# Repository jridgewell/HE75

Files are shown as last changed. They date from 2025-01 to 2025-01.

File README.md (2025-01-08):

# HE75

A standard 60% kebyoard (GH60 compatible) with 75 hall effects keys and an ortholinear layout.

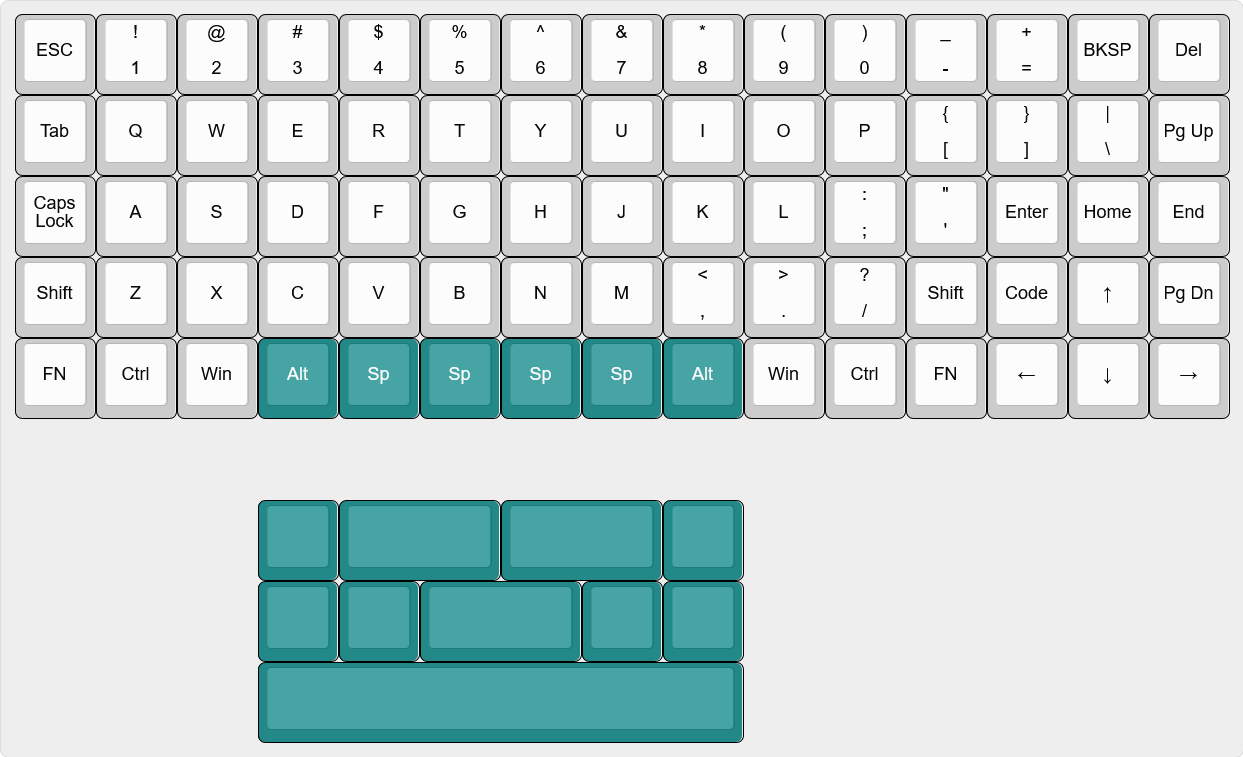
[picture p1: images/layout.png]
Keyboard Layout (https://www.keyboard-layout-editor.com/#/gists/170365ab19794ff094947c42b6bdc8db)

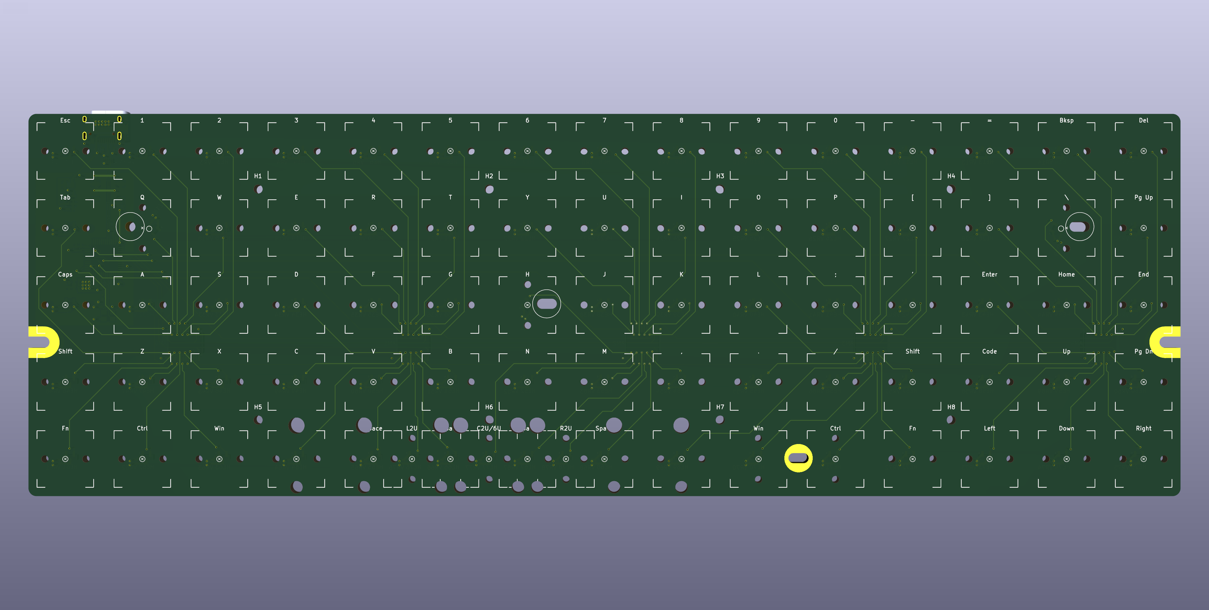
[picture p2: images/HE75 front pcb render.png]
Front PCB rendering

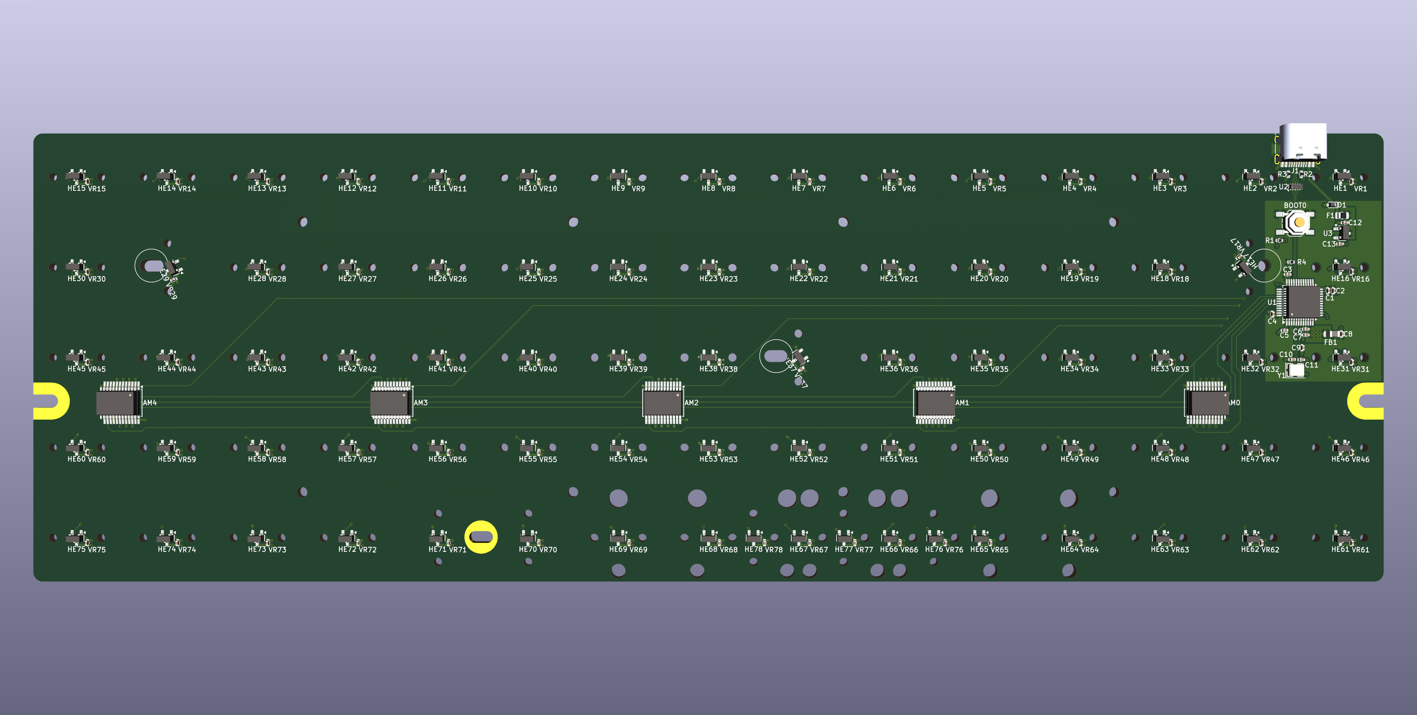
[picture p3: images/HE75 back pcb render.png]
Back PCB rendering


## Prior Art

While this keyboard is my own design, I pulled from many prior keyboard designs to figure out 60% layouts and how to layout hall effect sensors.

- [MoonBoard](https://github.com/certainly1182/MoonBoard), which I used heavily for routing patterns, schematic design, and even to find code to program QMK.
- [Void Switch 65%](https://github.com/riskable/void_switch_65_pct) (and the 2 begining videos [part 1](https://www.youtube.com/watch?v=TfKz_FbZWLQ) and [part 2](https://www.youtube.com/watch?v=sFR6E_Ejot0)), for giving me a starting point.
- [HE8](https://github.com/peppapighs/HE8) (and his [writeup](https://old.reddit.com/r/MechanicalKeyboards/comments/1glk0dc/i_made_a_hall_effect_macropad_long_writeup_below/)) to confirm components work.

I also used a few community assets to start the design:
- https://github.com/ebastler/marbastlib for switches and stabalizers footprints.
- https://github.com/ai03-2725/JP60 for an up-to-date GH60 shell layout.

# Constraints while designing

1. Must fit into a 60% keyboard case
2. Must use an ortholinear layout
3. Must use hall effect keys

I bought a [Wooting 60HE module](https://wooting.io/wooting-60he-module) and case, but I just can't stand the standard keyboard layout after using a split-ortho board for years. This is my attempt to cram an ortholinear layout into the same case, keeping it as close to a normal row staggered layout as possible. I do need occasional 1-handed access to right-hand side of the keyboard, I'm not after a mock split.

The first major issue is mouting positions for GH60 keyboards (marked in red):

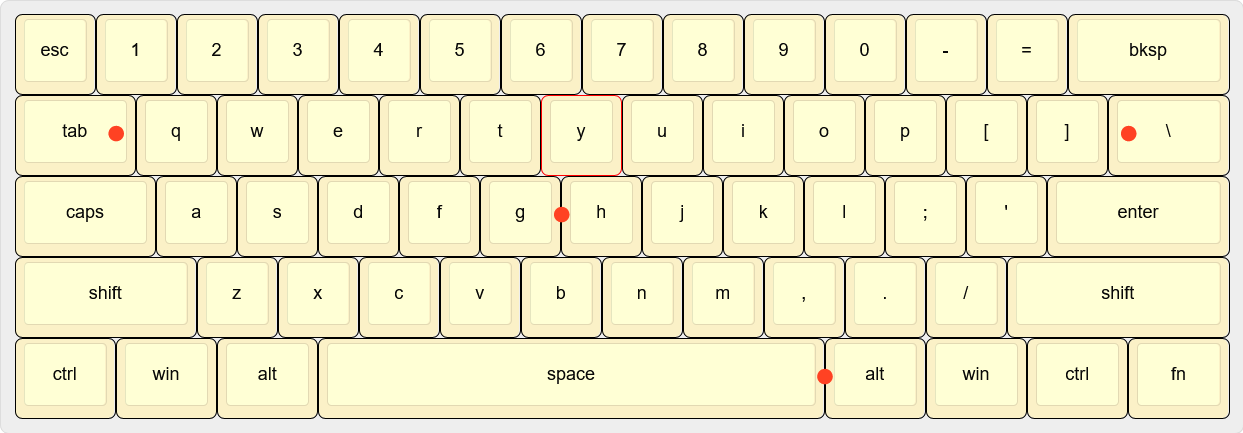
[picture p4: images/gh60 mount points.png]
GH60 mount points (https://www.keyboard-layout-editor.com/#/gists/9240d6fccecb17ad5743e3385da3a0a3)


When putting an ortholinear layout over top of that, several of the keys conflict:

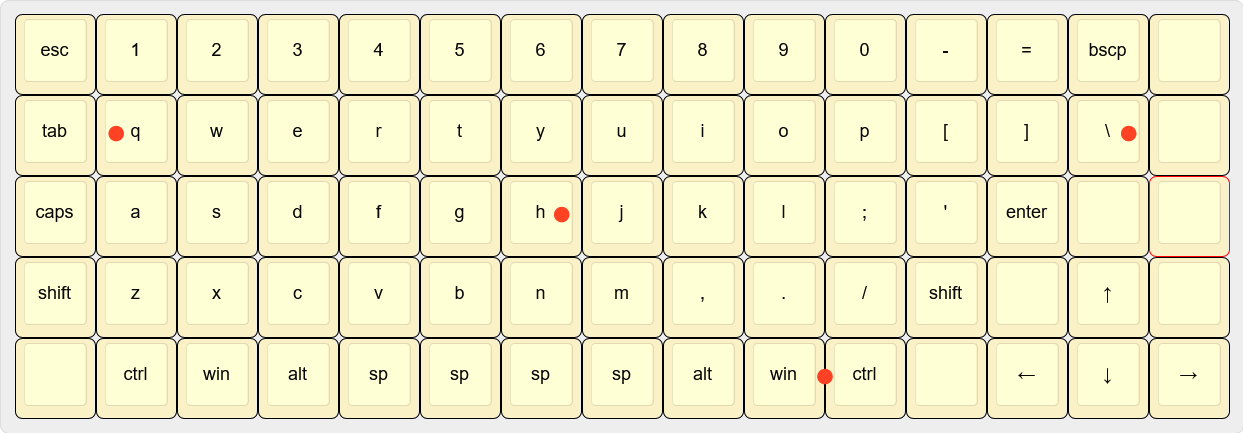
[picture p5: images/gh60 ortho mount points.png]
Ortho GH60 mount points (https://www.keyboard-layout-editor.com/#/gists/17eab835f870a1f1875c20cea78cf165)


If I were using standard MX key switches, this would only require rotating those keys 90% and skipping the screws in those locations. But with a hall effect keyboard, there's a hall effect sensor on the backside of the PCB occupying the same space as the screw mount. I need to move it so that it doesn't short out or get damaged when inserting the keyboard into the case. So for three keys (Q, H, and \), the sensor is roughly 1mm out of alignment with the key switch's magnet. Hopefully this'll be ok.

# Next Steps

I haven't ordered the first set of boards yet. JLCPCB estimates $47 for the first 5 PCBs, and $142 to get them assembled. I'm hoping someone will review the design before I send it off, I'm very new to this.

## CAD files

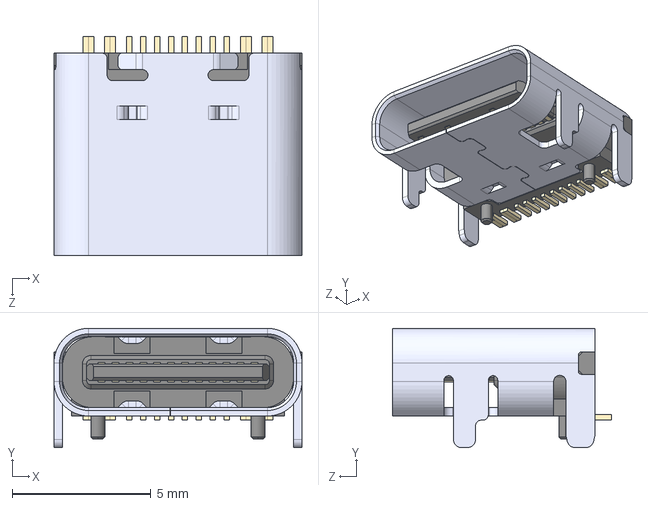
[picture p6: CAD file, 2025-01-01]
shapes3D/TYPE-C-31-M-12--3DModel-STEP-56544.STEP
8.94 x 4.30 x 7.90 mm

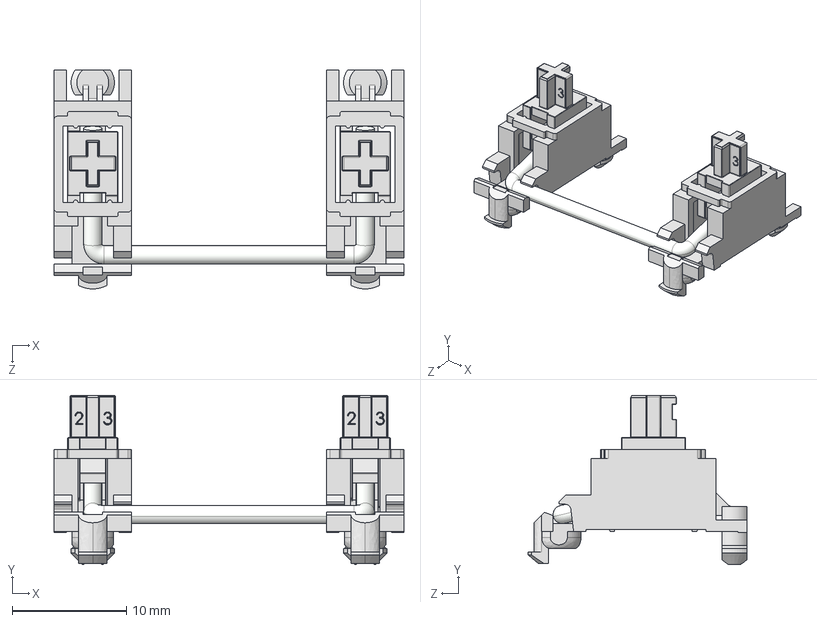
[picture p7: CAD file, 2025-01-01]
shapes3D/Stabilizer - close.STEP
30.7 x 14.9 x 19.2 mm
mx Stabilizer base 16828 x 2
mx Stabilizer key 16828 x 2
metal stick 16828

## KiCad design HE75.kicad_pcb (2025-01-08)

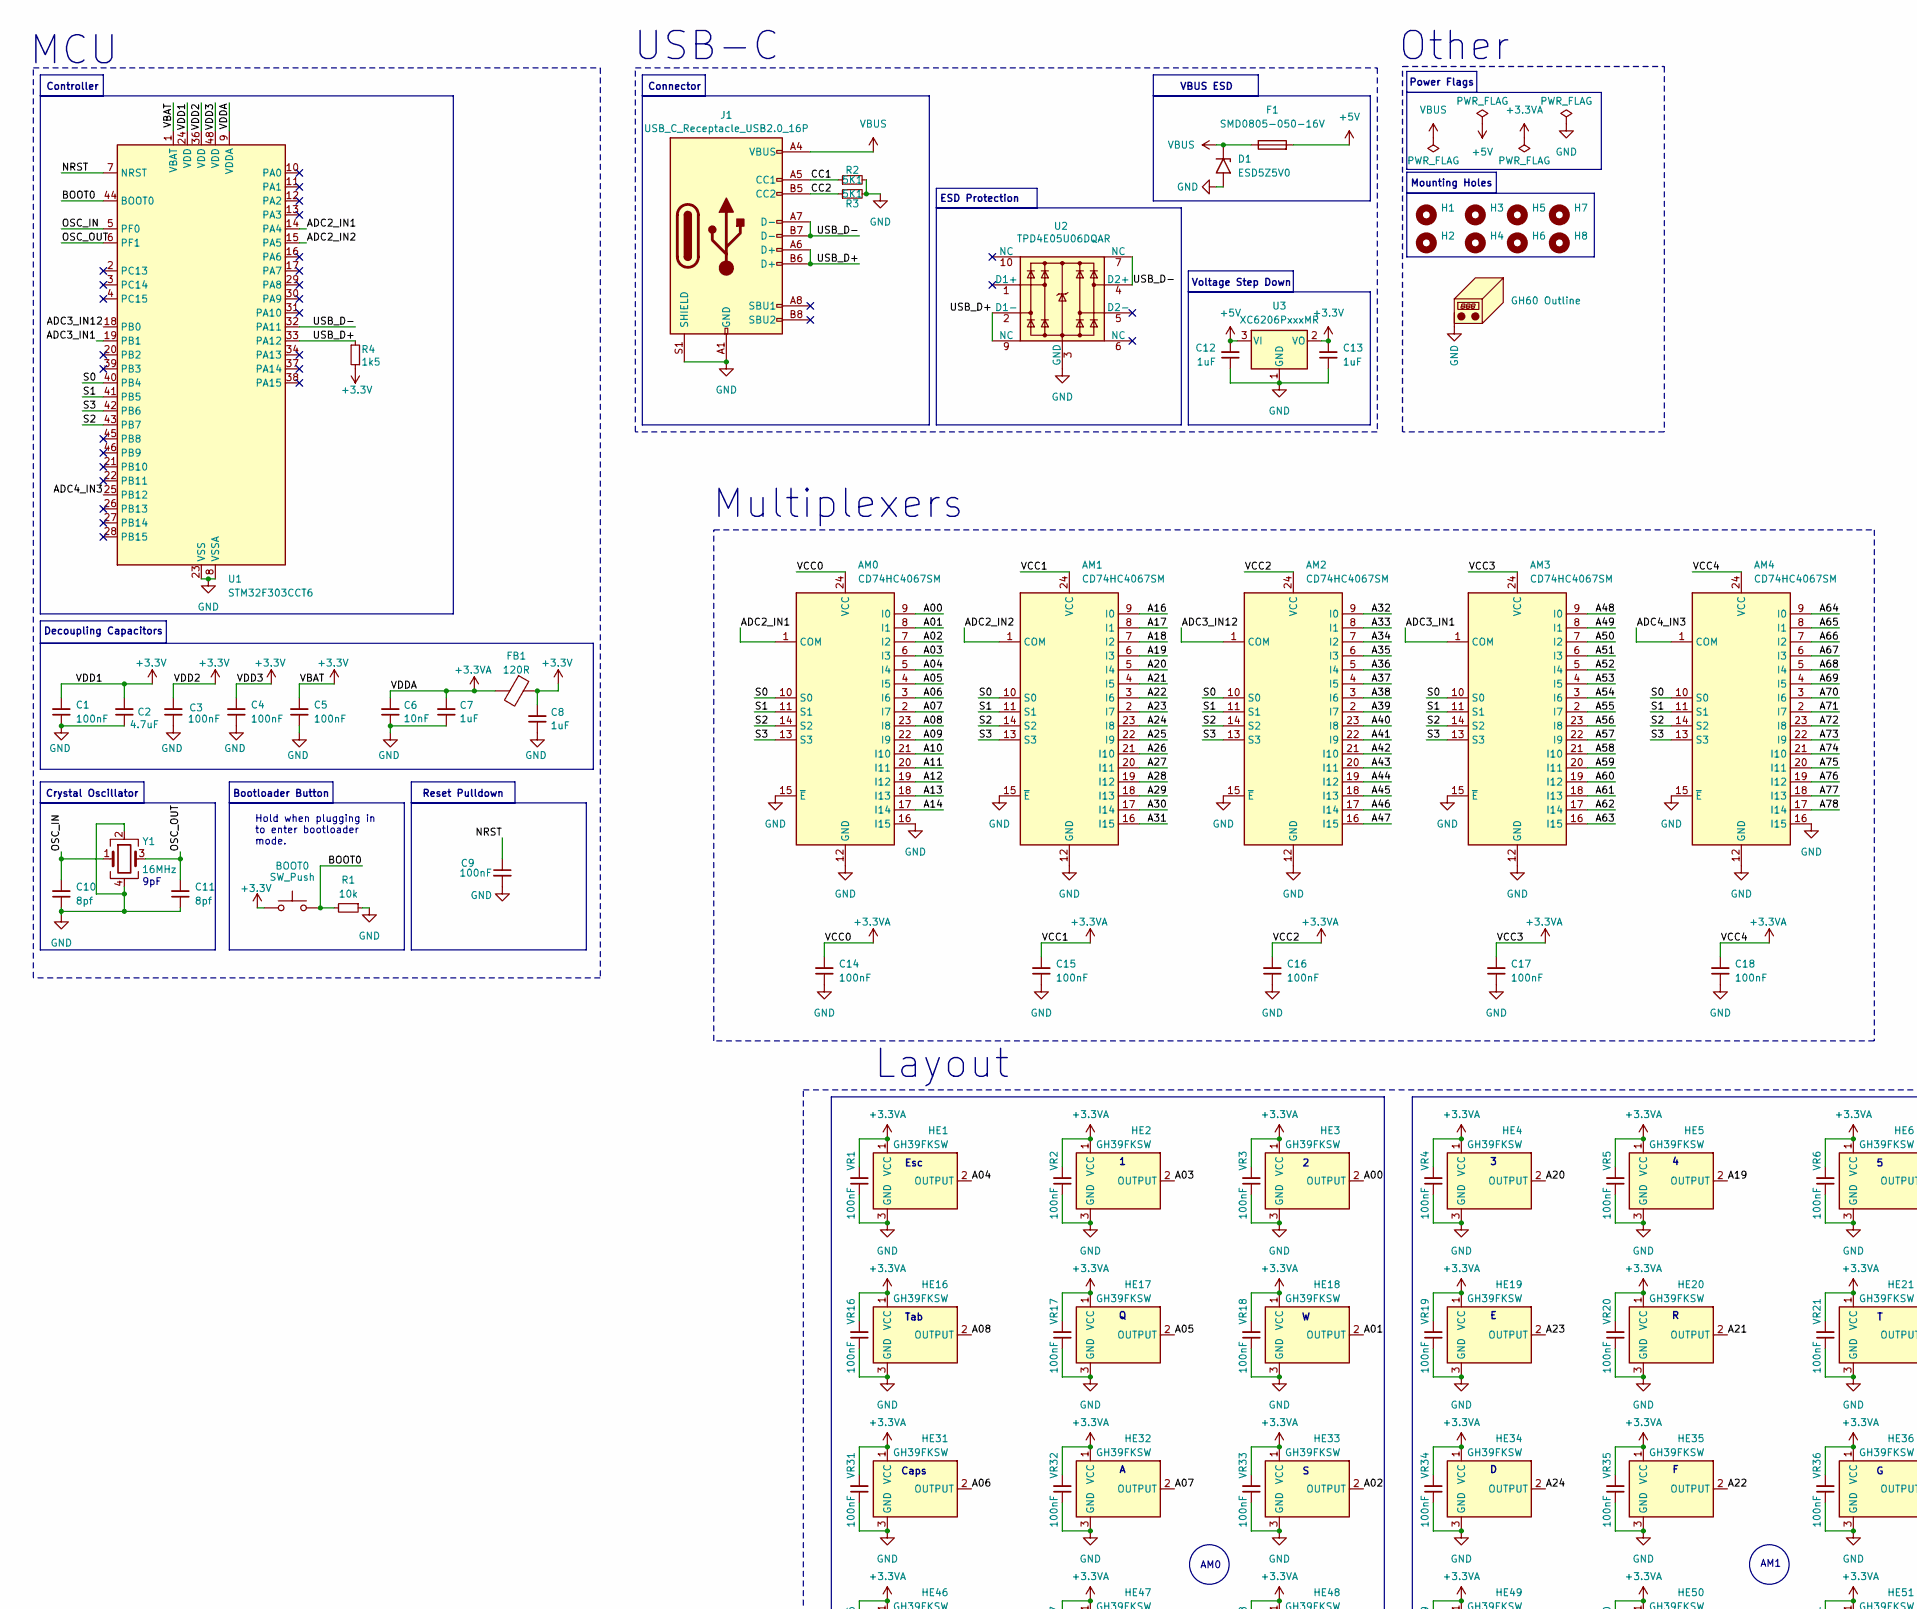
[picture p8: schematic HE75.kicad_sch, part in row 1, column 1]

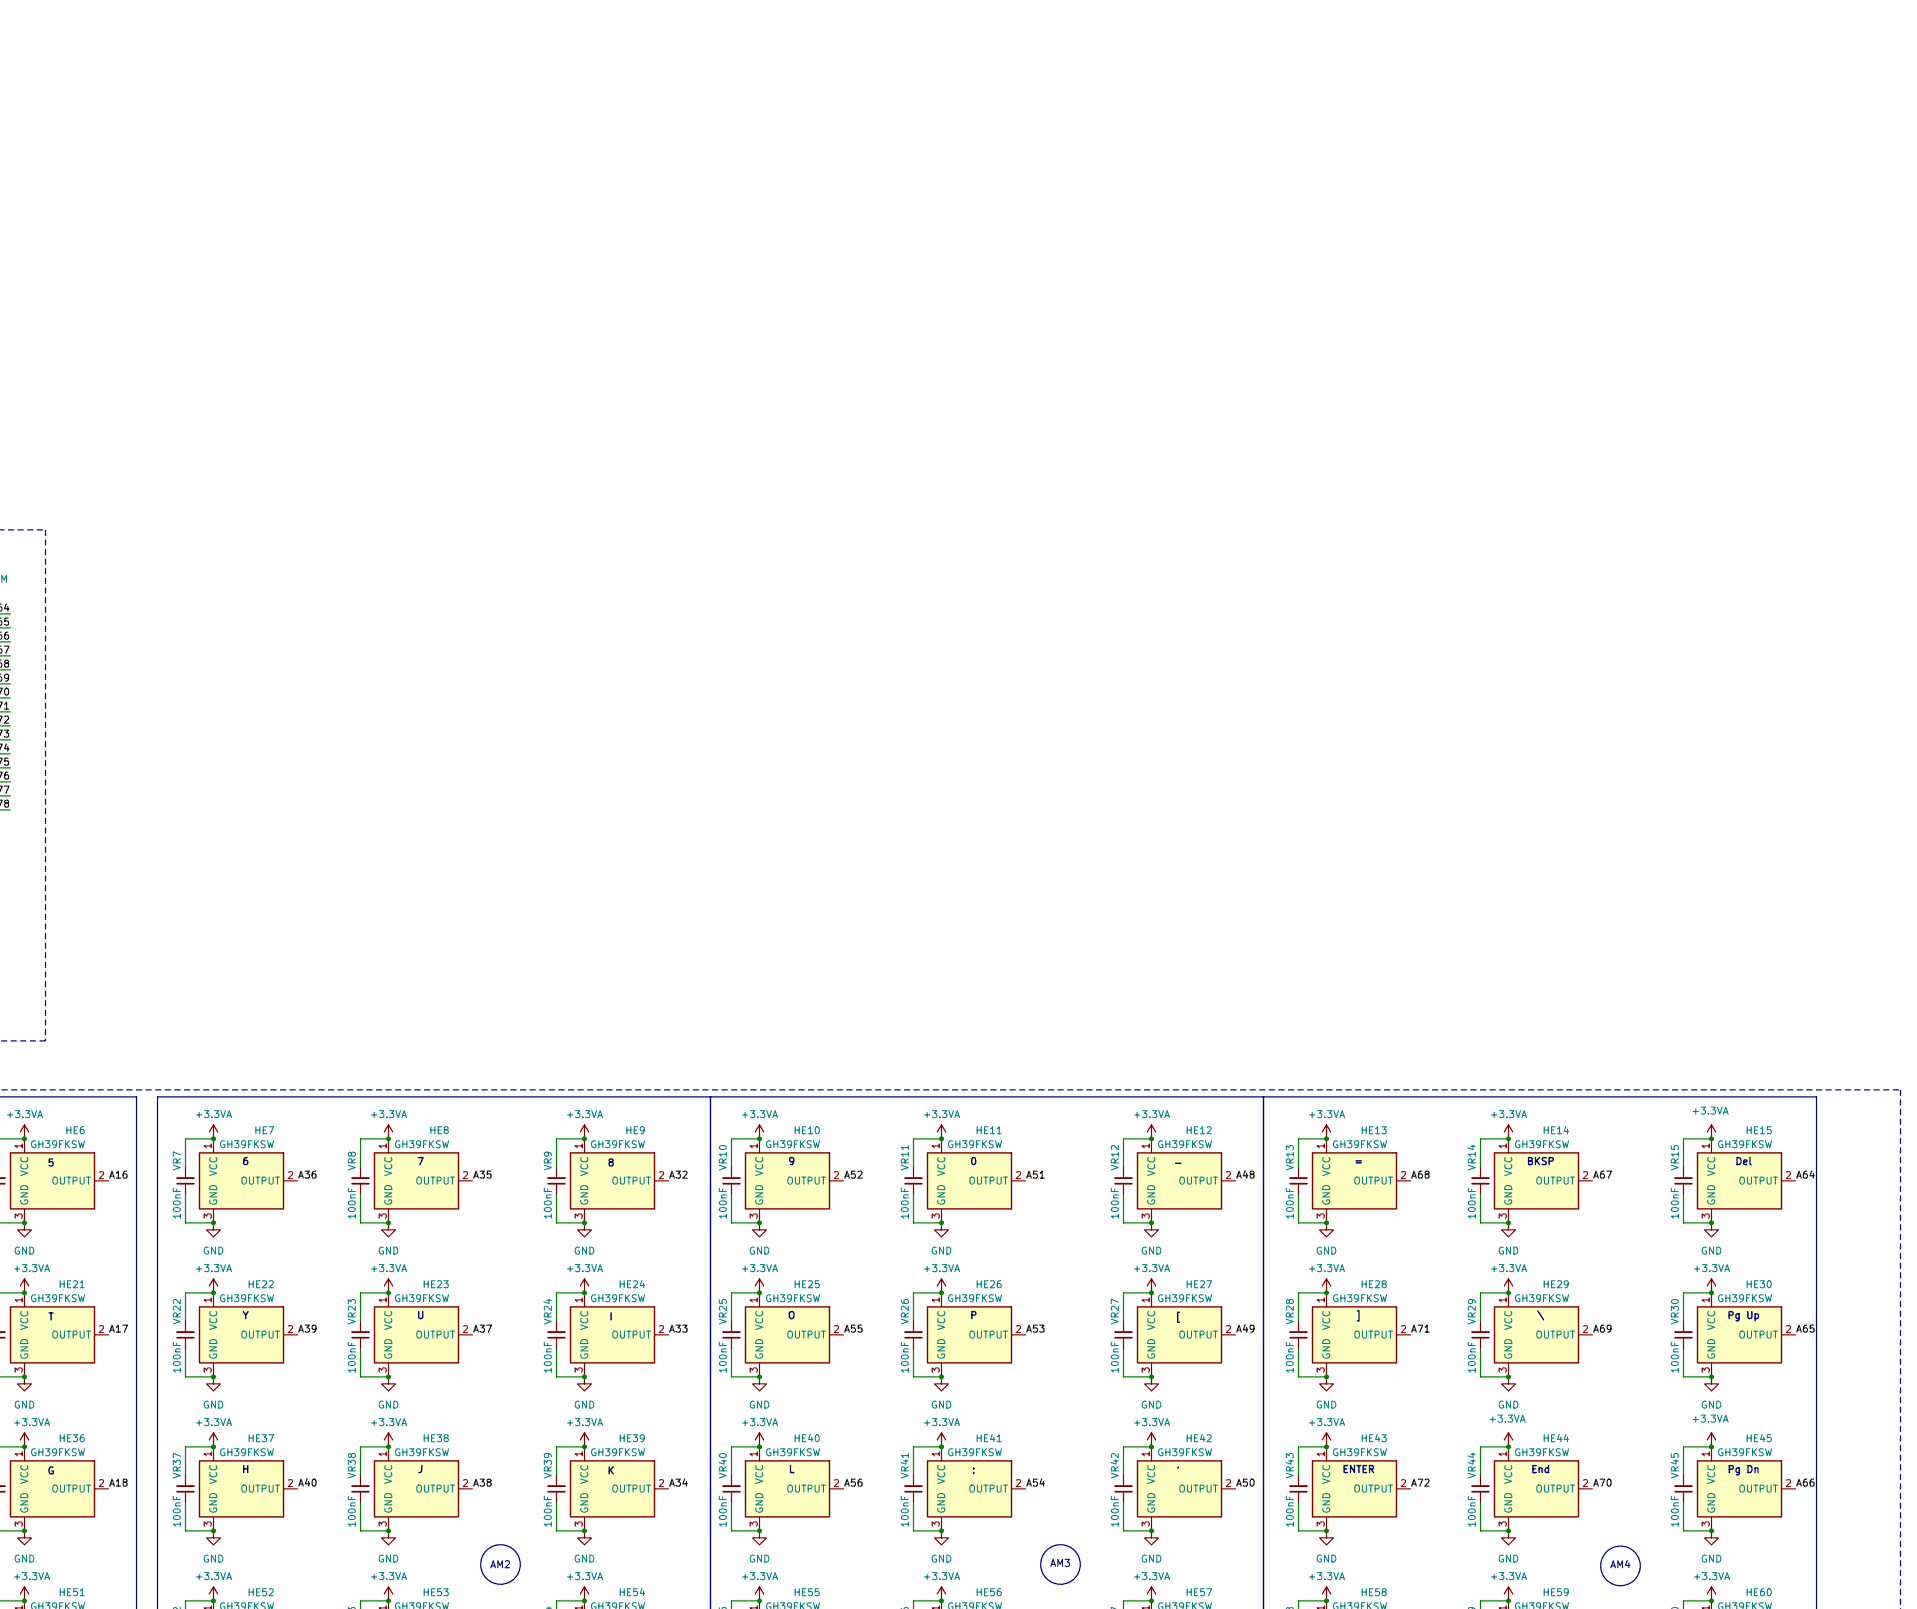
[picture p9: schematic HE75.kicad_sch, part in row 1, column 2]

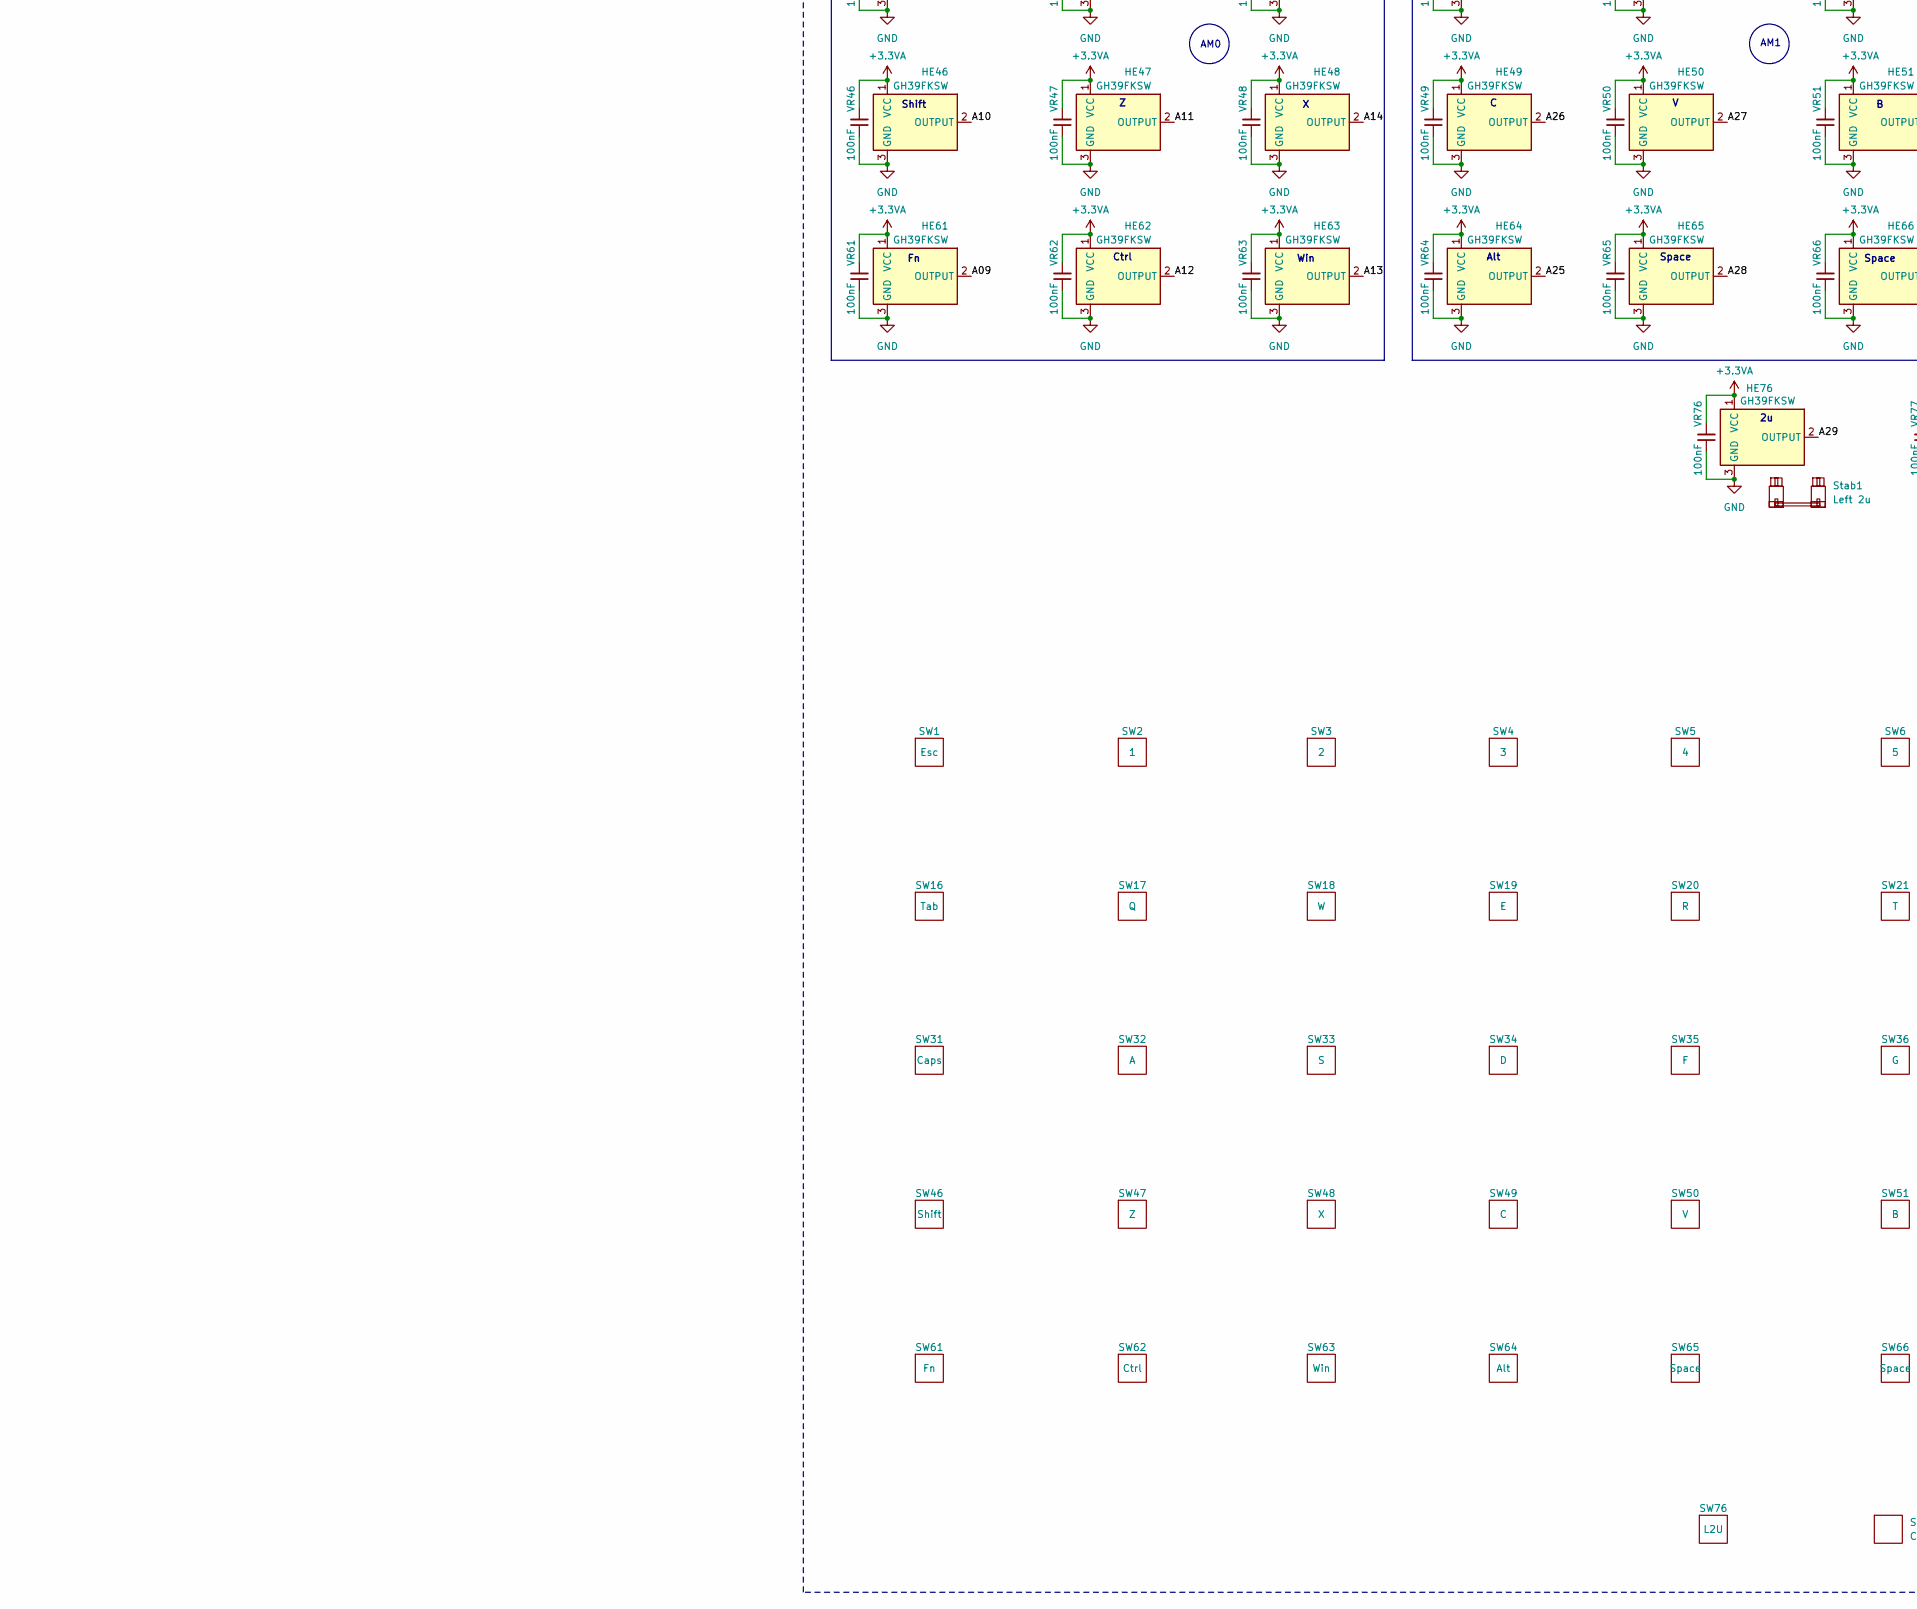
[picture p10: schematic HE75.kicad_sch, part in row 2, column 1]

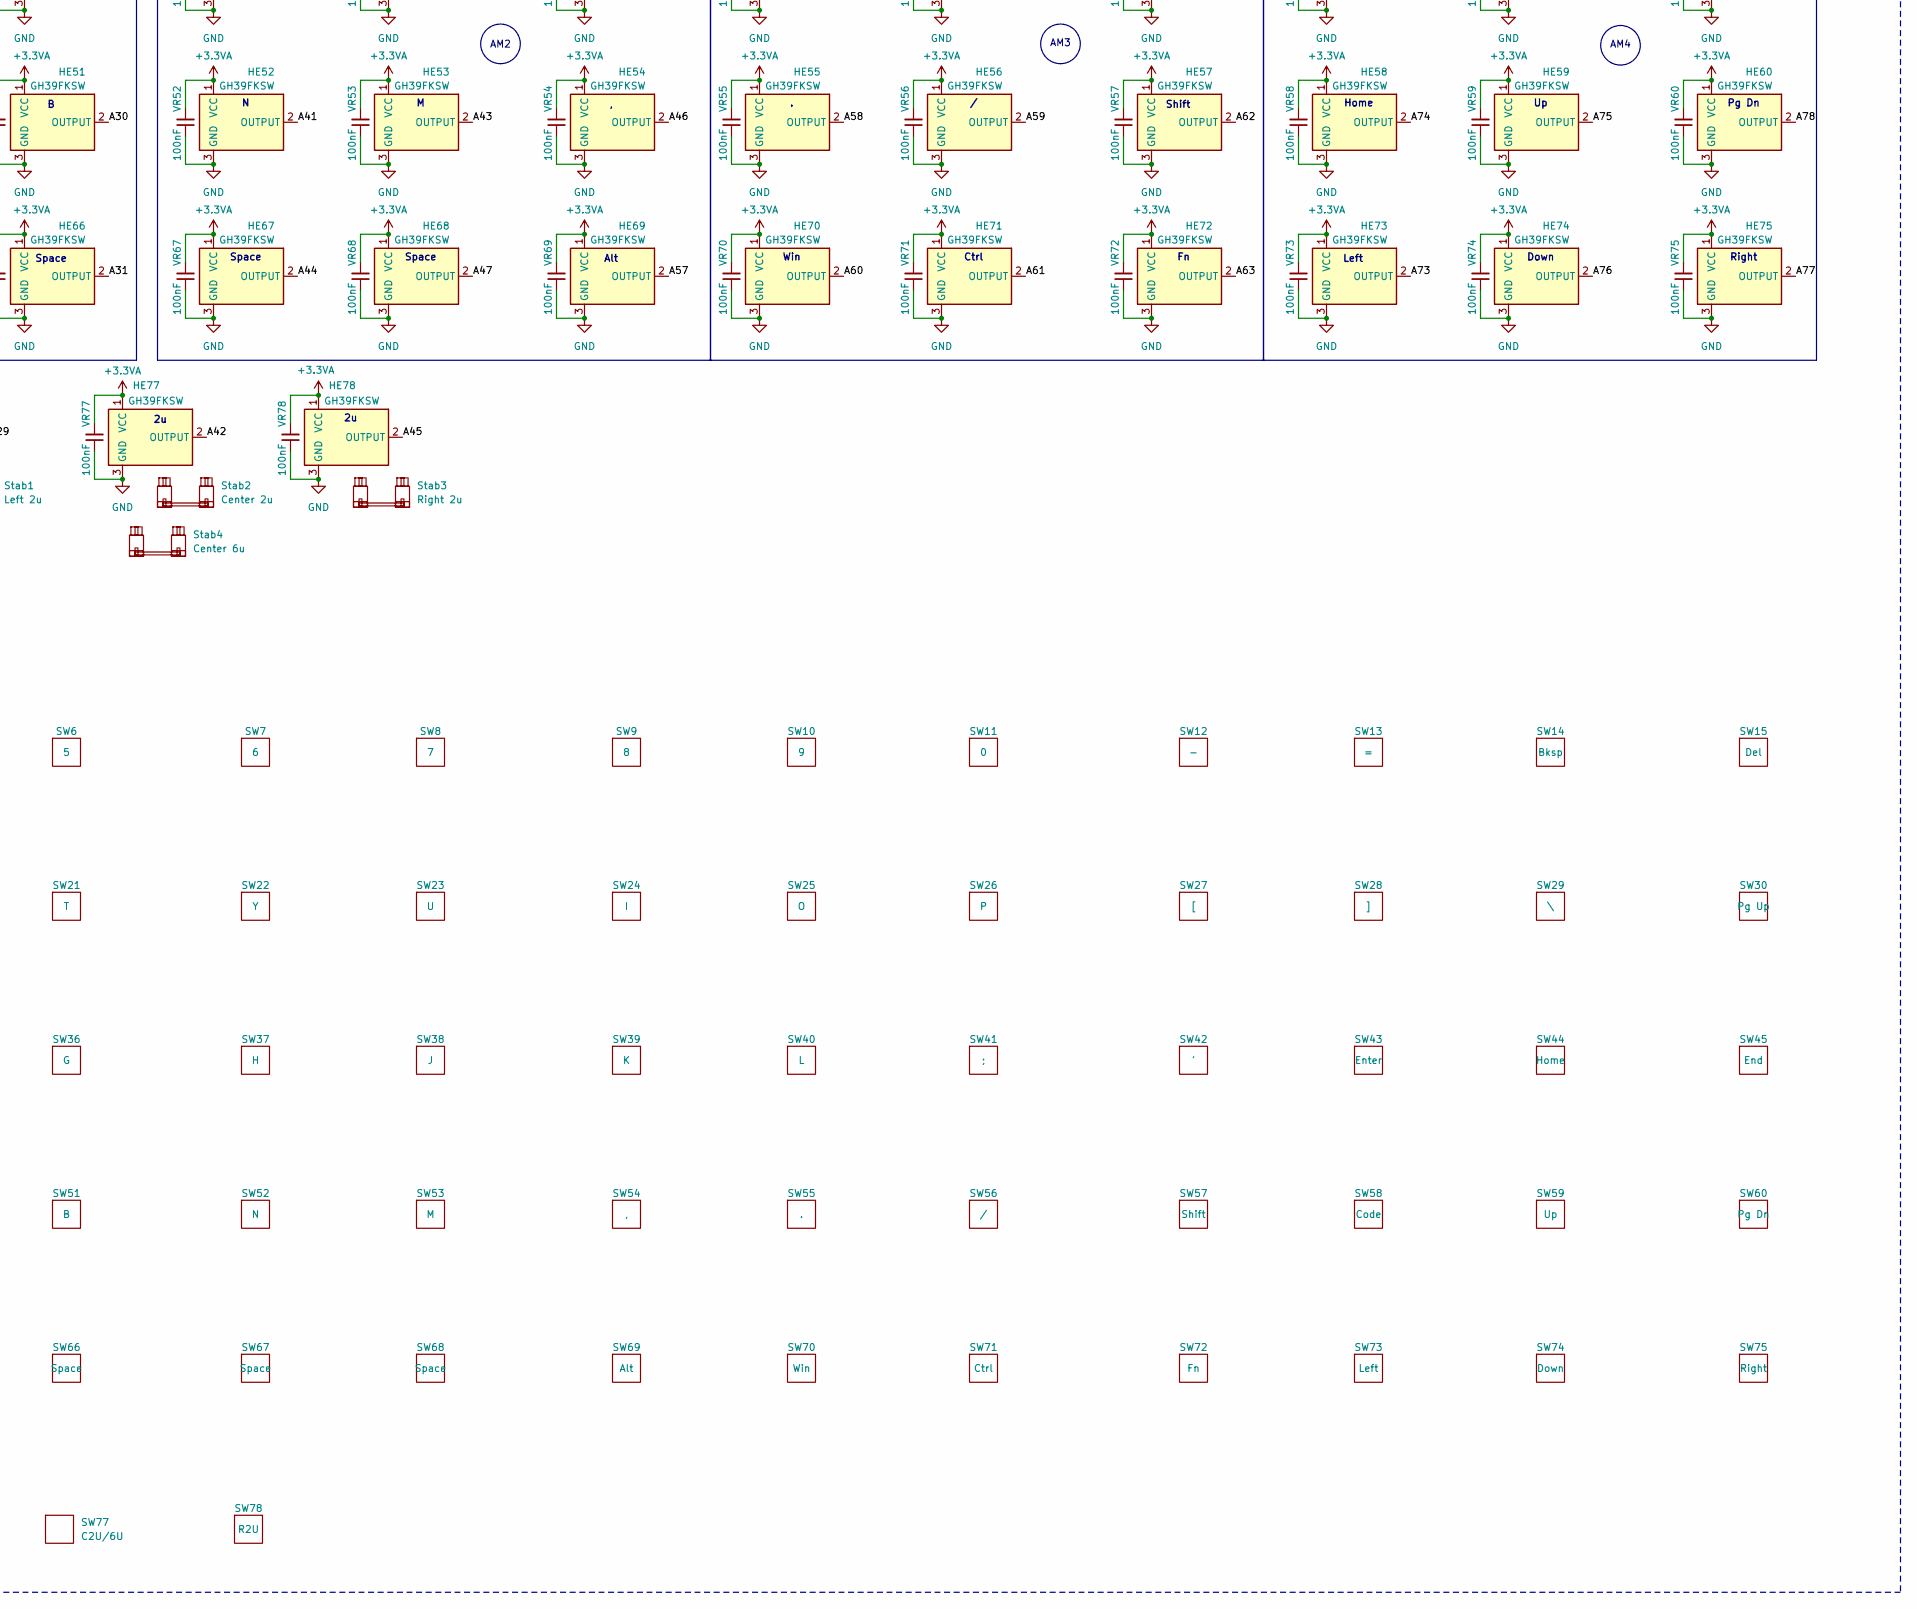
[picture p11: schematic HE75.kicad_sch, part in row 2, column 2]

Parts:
AM0, AM1, AM2, AM3, AM4: CD74HC4067SM; SSOP-24_5.3x8.2mm_P0.65mm; LCSC C98457
BOOT0: SW_Push; SW_SPST_TL3342; MPN SKQGABE010; LCSC C115351
C1, C3, C4, C5, C9, C14, C15, C16, C17, C18: 100nF; Capacitor 0402; LCSC C1525
C2: 4.7uF; Capacitor 0402; LCSC C23733
C6: 10nF; Capacitor 0402; LCSC C15195
C7, C8, C12, C13: 1uF; Capacitor 0402; LCSC C52923
C10, C11: 8pf; Capacitor 0402; LCSC C472443
D1: ESD5Z5V0; D_SOD-523; Manufacturer Part Number ESD5Z5V0; LCSC C502546
F1: SMD0805-050-16V; Fuse_0805_2012Metric; Manufacturer Part Number SMD0805-050-16V; LCSC C2833485
FB1: 120R; L_0805_2012Metric; LCSC C285922
H1, H2, H3, H4, H5, H6, H7, H8: MountingHole; MountingHole_2.2mm_M2
HE1, HE2, HE3, HE4, HE5, HE6, HE7, HE8, HE9, HE10, HE11, HE12, HE13, HE14, HE15, HE16, HE17, HE18, HE19, HE20, HE21, HE22, HE23, HE24, HE25, HE26, HE27, HE28, HE29, HE30, HE31, HE32, HE33, HE34, HE35, HE36, HE37, HE38, HE39, HE40, HE41, HE42, HE43, HE44, HE45, HE46, HE47, HE48, HE49, HE50, HE51, HE52, HE53, HE54, HE55, HE56, HE57, HE58, HE59, HE60, HE61, HE62, HE63, HE64, HE65, HE66, HE67, HE68, HE69, HE70, HE71, HE72, HE73, HE74, HE75, HE76, HE77, HE78: GH39FKSW; Hall Effect Sensor SOT-23; LCSC C266230
J1: USB_C_Receptacle_USB2.0_16P; USB_C_Receptacle_HRO_TYPE-C-31-M-12; MPN TYPE-C-31-M-12; LCSC C165948
O1: GH60 Outline; 60_Outline
R1: 10k; R_0402_1005Metric; LCSC C25744
R2, R3: 5K1; R_0402_1005Metric; LCSC C25905
R4: 1k5; R_0402_1005Metric; LCSC C25867
SW1: Esc; 1u MX Hall Effect
SW2: 1; 1u MX Hall Effect
SW3: 2; 1u MX Hall Effect
SW4: 3; 1u MX Hall Effect
SW5: 4; 1u MX Hall Effect
SW6: 5; 1u MX Hall Effect
SW7: 6; 1u MX Hall Effect
SW8: 7; 1u MX Hall Effect
SW9: 8; 1u MX Hall Effect
SW10: 9; 1u MX Hall Effect
SW11: 0; 1u MX Hall Effect
SW12: -; 1u MX Hall Effect
SW13: =; 1u MX Hall Effect
SW14: Bksp; 1u MX Hall Effect
SW15: Del; 1u MX Hall Effect
SW16: Tab; 1u MX Hall Effect
SW17: Q; 1u MX Hall Effect
SW18: W; 1u MX Hall Effect
SW19: E; 1u MX Hall Effect
SW20: R; 1u MX Hall Effect
SW21: T; 1u MX Hall Effect
SW22: Y; 1u MX Hall Effect
SW23: U; 1u MX Hall Effect
SW24: I; 1u MX Hall Effect
SW25: O; 1u MX Hall Effect
SW26: P; 1u MX Hall Effect
SW27: [; 1u MX Hall Effect
SW28: ]; 1u MX Hall Effect
SW29: \; 1u MX Hall Effect
SW30: Pg Up; 1u MX Hall Effect
SW31: Caps; 1u MX Hall Effect
SW32: A; 1u MX Hall Effect
SW33: S; 1u MX Hall Effect
SW34: D; 1u MX Hall Effect
SW35: F; 1u MX Hall Effect
SW36: G; 1u MX Hall Effect
SW37: H; 1u MX Hall Effect
SW38: J; 1u MX Hall Effect
SW39: K; 1u MX Hall Effect
SW40: L; 1u MX Hall Effect
SW41: ;; 1u MX Hall Effect
SW42: '; 1u MX Hall Effect
SW43: Enter; 1u MX Hall Effect
SW44: Home; 1u MX Hall Effect
SW45: End; 1u MX Hall Effect
SW46, SW57: Shift; 1u MX Hall Effect
SW47: Z; 1u MX Hall Effect
SW48: X; 1u MX Hall Effect
SW49: C; 1u MX Hall Effect
SW50: V; 1u MX Hall Effect
SW51: B; 1u MX Hall Effect
SW52: N; 1u MX Hall Effect
SW53: M; 1u MX Hall Effect
SW54: ,; 1u MX Hall Effect
SW55: .; 1u MX Hall Effect
SW56: /; 1u MX Hall Effect
SW58: Code; 1u MX Hall Effect
SW59: Up; 1u MX Hall Effect
SW60: Pg Dn; 1u MX Hall Effect
SW61, SW72: Fn; 1u MX Hall Effect
SW62, SW71: Ctrl; 1u MX Hall Effect
SW63, SW70: Win; 1u MX Hall Effect
SW64, SW69: Alt; 1u MX Hall Effect
SW65, SW66, SW67, SW68: Space; 1u MX Hall Effect
SW73: Left; 1u MX Hall Effect
SW74: Down; 1u MX Hall Effect
SW75: Right; 1u MX Hall Effect
SW76: L2U; 1u MX Hall Effect
SW77: C2U/6U; 1u MX Hall Effect
SW78: R2U; 1u MX Hall Effect
Stab1: Left 2u; STAB_MX_2u
Stab2: Center 2u; STAB_MX_2u
Stab3: Right 2u; STAB_MX_2u
Stab4: Center 6u; STAB_MX_6u
U1: STM32F303CCT6; LQFP-48_7x7mm_P0.5mm; LCSC C81523
U2: TPD4E05U06DQAR; USON-10_2.5x1.0mm_P0.5mm; LCSC C138714
U3: XC6206PxxxMR; SOT-23-3; MPN XC6206P332MR-G; LCSC C5446
VR1, VR2, VR3, VR4, VR5, VR6, VR7, VR8, VR9, VR10, VR11, VR12, VR13, VR14, VR15, VR16, VR17, VR18, VR19, VR20, VR21, VR22, VR23, VR24, VR25, VR26, VR27, VR28, VR29, VR30, VR31, VR32, VR33, VR34, VR35, VR36, VR37, VR38, VR39, VR40, VR41, VR42, VR43, VR44, VR45, VR46, VR47, VR48, VR49, VR50, VR51, VR52, VR53, VR54, VR55, VR56, VR57, VR58, VR59, VR60, VR61, VR62, VR63, VR64, VR65, VR66, VR67, VR68, VR69, VR70, VR71, VR72, VR73, VR74, VR75, VR76, VR77, VR78: 100nF; Capacitor 0402; LCSC C1525
Y1: 16MHz; Crystal_SMD_3225-4Pin_3.2x2.5mm; LCSC C13738

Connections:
+3.3V: BOOT0.1, C1.2, C2.2, C3.2, C4.2, C5.2, C8.2, C13.2, FB1.1, R4.2, U1.1 (VBAT), U1.24 (VDD), U1.36 (VDD), U1.48 (VDD), U3.2 (VO)
+3.3VA: AM0.24 (VCC), AM1.24 (VCC), AM2.24 (VCC), AM3.24 (VCC), AM4.24 (VCC), C6.2, C7.2, C14.2, C15.2, C16.2, C17.2, C18.2, FB1.2, HE1.1 (VCC), HE2.1 (VCC), HE3.1 (VCC), HE4.1 (VCC), HE5.1 (VCC), HE6.1 (VCC), HE7.1 (VCC), HE8.1 (VCC), HE9.1 (VCC), HE10.1 (VCC), HE11.1 (VCC), HE12.1 (VCC), HE13.1 (VCC), HE14.1 (VCC), HE15.1 (VCC), HE16.1 (VCC), HE17.1 (VCC), HE18.1 (VCC), HE19.1 (VCC), HE20.1 (VCC), HE21.1 (VCC), HE22.1 (VCC), HE23.1 (VCC), HE24.1 (VCC), HE25.1 (VCC), HE26.1 (VCC), HE27.1 (VCC), HE28.1 (VCC), HE29.1 (VCC), HE30.1 (VCC), HE31.1 (VCC), HE32.1 (VCC), HE33.1 (VCC), HE34.1 (VCC), HE35.1 (VCC), HE36.1 (VCC), HE37.1 (VCC), HE38.1 (VCC), HE39.1 (VCC), HE40.1 (VCC), HE41.1 (VCC), HE42.1 (VCC), HE43.1 (VCC), HE44.1 (VCC), HE45.1 (VCC), HE46.1 (VCC), HE47.1 (VCC), HE48.1 (VCC), HE49.1 (VCC), HE50.1 (VCC), HE51.1 (VCC), HE52.1 (VCC), HE53.1 (VCC), HE54.1 (VCC), HE55.1 (VCC), HE56.1 (VCC), HE57.1 (VCC), HE58.1 (VCC), HE59.1 (VCC), HE60.1 (VCC), HE61.1 (VCC), HE62.1 (VCC), HE63.1 (VCC), HE64.1 (VCC), HE65.1 (VCC), HE66.1 (VCC), HE67.1 (VCC), HE68.1 (VCC), HE69.1 (VCC), HE70.1 (VCC), HE71.1 (VCC), HE72.1 (VCC), HE73.1 (VCC), HE74.1 (VCC), HE75.1 (VCC), HE76.1 (VCC), HE77.1 (VCC), HE78.1 (VCC), U1.9 (VDDA), VR1.2, VR2.2, VR3.2, VR4.2, VR5.2, VR6.2, VR7.2, VR8.2, VR9.2, VR10.2, VR11.2, VR12.2, VR13.2, VR14.2, VR15.2, VR16.2, VR17.2, VR18.2, VR19.2, VR20.2, VR21.2, VR22.2, VR23.2, VR24.2, VR25.2, VR26.2, VR27.2, VR28.2, VR29.2, VR30.2, VR31.2, VR32.2, VR33.2, VR34.2, VR35.2, VR36.2, VR37.2, VR38.2, VR39.2, VR40.2, VR41.2, VR42.2, VR43.2, VR44.2, VR45.2, VR46.2, VR47.2, VR48.2, VR49.2, VR50.2, VR51.2, VR52.2, VR53.2, VR54.2, VR55.2, VR56.2, VR57.2, VR58.2, VR59.2, VR60.2, VR61.2, VR62.2, VR63.2, VR64.2, VR65.2, VR66.2, VR67.2, VR68.2, VR69.2, VR70.2, VR71.2, VR72.2, VR73.2, VR74.2, VR75.2, VR76.2, VR77.2, VR78.2
+5V: C12.2, F1.2, U3.3 (VI)
/A00: AM0.9 (I0), HE3.2 (OUTPUT)
/A01: AM0.8 (I1), HE18.2 (OUTPUT)
/A02: AM0.7 (I2), HE33.2 (OUTPUT)
/A03: AM0.6 (I3), HE2.2 (OUTPUT)
/A04: AM0.5 (I4), HE1.2 (OUTPUT)
/A05: AM0.4 (I5), HE17.2 (OUTPUT)
/A06: AM0.3 (I6), HE31.2 (OUTPUT)
/A07: AM0.2 (I7), HE32.2 (OUTPUT)
/A08: AM0.23 (I8), HE16.2 (OUTPUT)
/A09: AM0.22 (I9), HE61.2 (OUTPUT)
/A10: AM0.21 (I10), HE46.2 (OUTPUT)
/A11: AM0.20 (I11), HE47.2 (OUTPUT)
/A12: AM0.19 (I12), HE62.2 (OUTPUT)
/A13: AM0.18 (I13), HE63.2 (OUTPUT)
/A14: AM0.17 (I14), HE48.2 (OUTPUT)
/A16: AM1.9 (I0), HE6.2 (OUTPUT)
/A17: AM1.8 (I1), HE21.2 (OUTPUT)
/A18: AM1.7 (I2), HE36.2 (OUTPUT)
/A19: AM1.6 (I3), HE5.2 (OUTPUT)
/A20: AM1.5 (I4), HE4.2 (OUTPUT)
/A21: AM1.4 (I5), HE20.2 (OUTPUT)
/A22: AM1.3 (I6), HE35.2 (OUTPUT)
/A23: AM1.2 (I7), HE19.2 (OUTPUT)
/A24: AM1.23 (I8), HE34.2 (OUTPUT)
/A25: AM1.22 (I9), HE64.2 (OUTPUT)
/A26: AM1.21 (I10), HE49.2 (OUTPUT)
/A27: AM1.20 (I11), HE50.2 (OUTPUT)
/A28: AM1.19 (I12), HE65.2 (OUTPUT)
/A29: AM1.18 (I13), HE76.2 (OUTPUT)
/A30: AM1.17 (I14), HE51.2 (OUTPUT)
/A31: AM1.16 (I15), HE66.2 (OUTPUT)
/A32: AM2.9 (I0), HE9.2 (OUTPUT)
/A33: AM2.8 (I1), HE24.2 (OUTPUT)
/A34: AM2.7 (I2), HE39.2 (OUTPUT)
/A35: AM2.6 (I3), HE8.2 (OUTPUT)
/A36: AM2.5 (I4), HE7.2 (OUTPUT)
/A37: AM2.4 (I5), HE23.2 (OUTPUT)
/A38: AM2.3 (I6), HE38.2 (OUTPUT)
/A39: AM2.2 (I7), HE22.2 (OUTPUT)
/A40: AM2.23 (I8), HE37.2 (OUTPUT)
/A41: AM2.22 (I9), HE52.2 (OUTPUT)
/A42: AM2.21 (I10), HE77.2 (OUTPUT)
/A43: AM2.20 (I11), HE53.2 (OUTPUT)
/A44: AM2.19 (I12), HE67.2 (OUTPUT)
/A45: AM2.18 (I13), HE78.2 (OUTPUT)
/A46: AM2.17 (I14), HE54.2 (OUTPUT)
/A47: AM2.16 (I15), HE68.2 (OUTPUT)
/A48: AM3.9 (I0), HE12.2 (OUTPUT)
/A49: AM3.8 (I1), HE27.2 (OUTPUT)
/A50: AM3.7 (I2), HE42.2 (OUTPUT)
/A51: AM3.6 (I3), HE11.2 (OUTPUT)
/A52: AM3.5 (I4), HE10.2 (OUTPUT)
/A53: AM3.4 (I5), HE26.2 (OUTPUT)
/A54: AM3.3 (I6), HE41.2 (OUTPUT)
/A55: AM3.2 (I7), HE25.2 (OUTPUT)
/A56: AM3.23 (I8), HE40.2 (OUTPUT)
/A57: AM3.22 (I9), HE69.2 (OUTPUT)
/A58: AM3.21 (I10), HE55.2 (OUTPUT)
/A59: AM3.20 (I11), HE56.2 (OUTPUT)
/A60: AM3.19 (I12), HE70.2 (OUTPUT)
/A61: AM3.18 (I13), HE71.2 (OUTPUT)
/A62: AM3.17 (I14), HE57.2 (OUTPUT)
/A63: AM3.16 (I15), HE72.2 (OUTPUT)
/A64: AM4.9 (I0), HE15.2 (OUTPUT)
/A65: AM4.8 (I1), HE30.2 (OUTPUT)
/A66: AM4.7 (I2), HE45.2 (OUTPUT)
/A67: AM4.6 (I3), HE14.2 (OUTPUT)
/A68: AM4.5 (I4), HE13.2 (OUTPUT)
/A69: AM4.4 (I5), HE29.2 (OUTPUT)
/A70: AM4.3 (I6), HE44.2 (OUTPUT)
/A71: AM4.2 (I7), HE28.2 (OUTPUT)
/A72: AM4.23 (I8), HE43.2 (OUTPUT)
/A73: AM4.22 (I9), HE73.2 (OUTPUT)
/A74: AM4.21 (I10), HE58.2 (OUTPUT)
/A75: AM4.20 (I11), HE59.2 (OUTPUT)
/A76: AM4.19 (I12), HE74.2 (OUTPUT)
/A77: AM4.18 (I13), HE75.2 (OUTPUT)
/A78: AM4.17 (I14), HE60.2 (OUTPUT)
/ADC2_IN1: AM0.1 (COM), U1.14 (PA4)
/ADC2_IN2: AM1.1 (COM), U1.15 (PA5)
/ADC3_IN1: AM3.1 (COM), U1.19 (PB1)
/ADC3_IN12: AM2.1 (COM), U1.18 (PB0)
/ADC4_IN3: AM4.1 (COM), U1.25 (PB12)
/BOOT0: BOOT0.2, R1.2, U1.44 (BOOT0)
/CC1: J1.A5 (CC1), R2.1
/CC2: J1.B5 (CC2), R3.1
/NRST: C9.1, U1.7 (NRST)
/OSC_IN: C10.2, U1.5 (PF0), Y1.1
/OSC_OUT: C11.2, U1.6 (PF1), Y1.3
/S0: AM0.10 (S0), AM1.10 (S0), AM2.10 (S0), AM3.10 (S0), AM4.10 (S0), U1.40 (PB4)
/S1: AM0.11 (S1), AM1.11 (S1), AM2.11 (S1), AM3.11 (S1), AM4.11 (S1), U1.41 (PB5)
/S2: AM0.14 (S2), AM1.14 (S2), AM2.14 (S2), AM3.14 (S2), AM4.14 (S2), U1.43 (PB7)
/S3: AM0.13 (S3), AM1.13 (S3), AM2.13 (S3), AM3.13 (S3), AM4.13 (S3), U1.42 (PB6)
/USB_D+: J1.A6 (D+), J1.B6 (D+), R4.1, U1.33 (PA12), U2.2 (D1-), U2.9 (NC)
/USB_D-: J1.A7 (D-), J1.B7 (D-), U1.32 (PA11), U2.4 (D2+), U2.7 (NC)
GND: AM0.12 (GND), AM0.15 (~E), AM0.16 (I15), AM1.12 (GND), AM1.15 (~E), AM2.12 (GND), AM2.15 (~E), AM3.12 (GND), AM3.15 (~E), AM4.12 (GND), AM4.15 (~E), AM4.16 (I15), C1.1, C2.1, C3.1, C4.1, C5.1, C6.1, C7.1, C8.1, C9.2, C10.1, C11.1, C12.1, C13.1, C14.1, C15.1, C16.1, C17.1, C18.1, D1.2 (A2), HE1.3 (GND), HE2.3 (GND), HE3.3 (GND), HE4.3 (GND), HE5.3 (GND), HE6.3 (GND), HE7.3 (GND), HE8.3 (GND), HE9.3 (GND), HE10.3 (GND), HE11.3 (GND), HE12.3 (GND), HE13.3 (GND), HE14.3 (GND), HE15.3 (GND), HE16.3 (GND), HE17.3 (GND), HE18.3 (GND), HE19.3 (GND), HE20.3 (GND), HE21.3 (GND), HE22.3 (GND), HE23.3 (GND), HE24.3 (GND), HE25.3 (GND), HE26.3 (GND), HE27.3 (GND), HE28.3 (GND), HE29.3 (GND), HE30.3 (GND), HE31.3 (GND), HE32.3 (GND), HE33.3 (GND), HE34.3 (GND), HE35.3 (GND), HE36.3 (GND), HE37.3 (GND), HE38.3 (GND), HE39.3 (GND), HE40.3 (GND), HE41.3 (GND), HE42.3 (GND), HE43.3 (GND), HE44.3 (GND), HE45.3 (GND), HE46.3 (GND), HE47.3 (GND), HE48.3 (GND), HE49.3 (GND), HE50.3 (GND), HE51.3 (GND), HE52.3 (GND), HE53.3 (GND), HE54.3 (GND), HE55.3 (GND), HE56.3 (GND), HE57.3 (GND), HE58.3 (GND), HE59.3 (GND), HE60.3 (GND), HE61.3 (GND), HE62.3 (GND), HE63.3 (GND), HE64.3 (GND), HE65.3 (GND), HE66.3 (GND), HE67.3 (GND), HE68.3 (GND), HE69.3 (GND), HE70.3 (GND), HE71.3 (GND), HE72.3 (GND), HE73.3 (GND), HE74.3 (GND), HE75.3 (GND), HE76.3 (GND), HE77.3 (GND), HE78.3 (GND), J1.A1 (GND), J1.A12 (GND), J1.B1 (GND), J1.B12 (GND), J1.S1 (SHIELD), O1.1 (PAD), R1.1, R2.2, R3.2, U1.8 (VSSA), U1.23 (VSS), U1.35 (VSS), U1.47 (VSS), U2.3 (GND), U2.8 (GND), U3.1 (GND), VR1.1, VR2.1, VR3.1, VR4.1, VR5.1, VR6.1, VR7.1, VR8.1, VR9.1, VR10.1, VR11.1, VR12.1, VR13.1, VR14.1, VR15.1, VR16.1, VR17.1, VR18.1, VR19.1, VR20.1, VR21.1, VR22.1, VR23.1, VR24.1, VR25.1, VR26.1, VR27.1, VR28.1, VR29.1, VR30.1, VR31.1, VR32.1, VR33.1, VR34.1, VR35.1, VR36.1, VR37.1, VR38.1, VR39.1, VR40.1, VR41.1, VR42.1, VR43.1, VR44.1, VR45.1, VR46.1, VR47.1, VR48.1, VR49.1, VR50.1, VR51.1, VR52.1, VR53.1, VR54.1, VR55.1, VR56.1, VR57.1, VR58.1, VR59.1, VR60.1, VR61.1, VR62.1, VR63.1, VR64.1, VR65.1, VR66.1, VR67.1, VR68.1, VR69.1, VR70.1, VR71.1, VR72.1, VR73.1, VR74.1, VR75.1, VR76.1, VR77.1, VR78.1, Y1.2, Y1.4
VBUS: D1.1 (A1), F1.1, J1.A4 (VBUS), J1.A9 (VBUS), J1.B4 (VBUS), J1.B9 (VBUS)

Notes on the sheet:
Hold when plugging in to enter bootloader mode.
Pg Up
Pg Dn
Alt
BKSP
Home
MCU
Del
Space
Caps
USB-C
Mounting Holes
Layout
9pF
Down
Multiplexers
Decoupling Capacitors
AM0
Controller
Reset Pulldown
Shift
Crystal Oscillator
ESD Protection
Ctrl
Esc
Power Flags
Voltage Step Down
Win
AM3
VBUS ESD
Left
Right
AM2
Other
ENTER
AM4
Bootloader Button
AM1
Tab
End

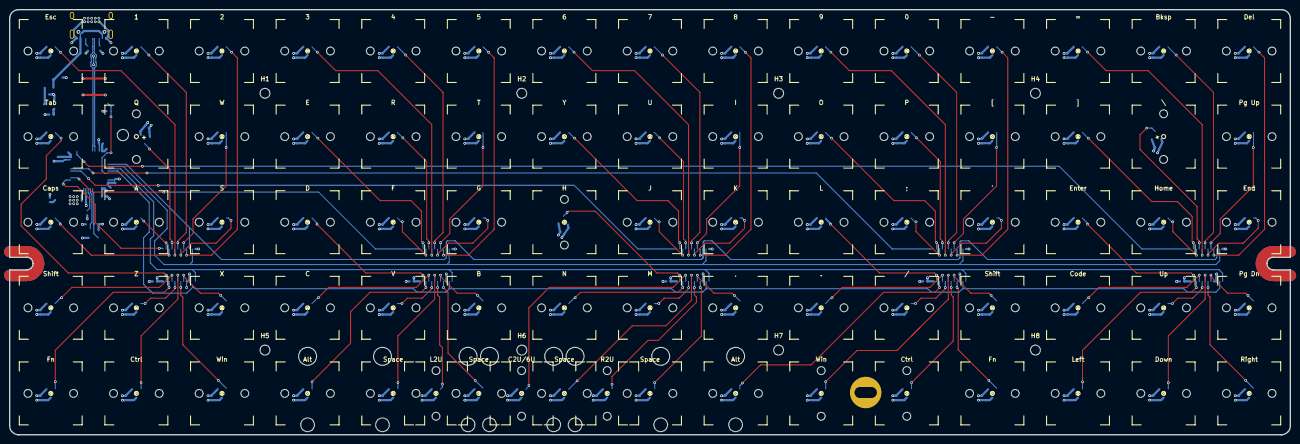
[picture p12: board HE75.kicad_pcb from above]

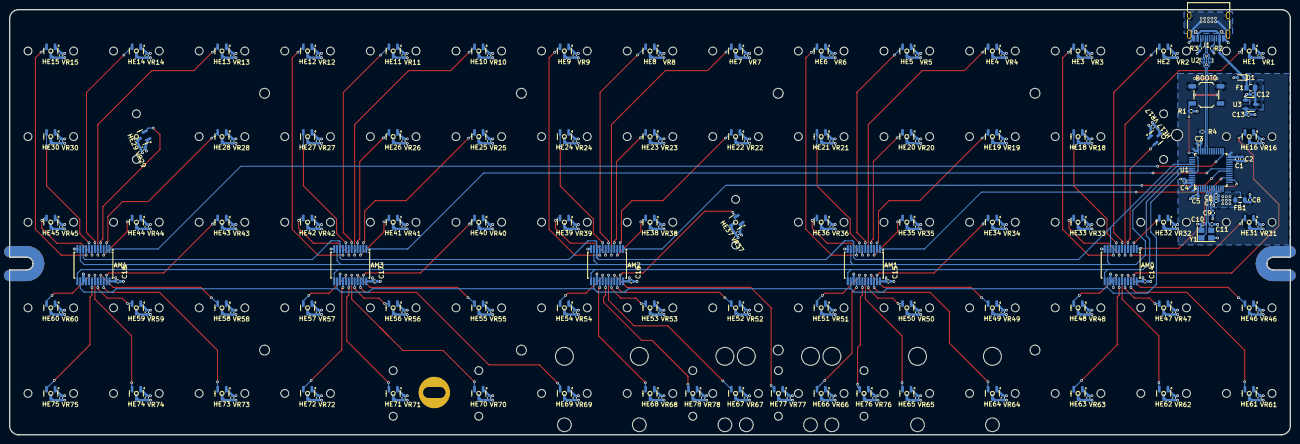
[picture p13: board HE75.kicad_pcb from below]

Board: 4 copper layers, 285.0 x 94.6 mm, 283 parts (192 on the bottom side), 100 nets.

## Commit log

2025-01-02 Fix sot-143b footprint
    [HE75.kicad_pcb, HE75.kicad_sch]
2025-01-04 Before attempting MCU rotation
    [HE75.kicad_pcb, HE75.kicad_sch]
2025-01-05 Add 6u spacebar stabalizers
    [HE75.kicad_pcb, HE75.kicad_sch]
2025-01-05 Adjusting tracks and silkscreens
    [HE75.kicad_pcb, HE75.kicad_sch]
2025-01-05 Fixes for JLCPCB
    [HE75.kicad_pcb, HE75.kicad_sch]
2025-01-05 Rotate silkscreens
    [HE75.kicad_pcb]
2025-01-05 Slightly adjust track routing
    [HE75.kicad_pcb]
2025-01-08 Adjust centering silkscreens
    [HE75.kicad_pcb, HE75.kicad_sch]
2025-01-08 Remove unused footprint
2025-01-08 Add decoupling capacitors to analog multiplexers
    [HE75.kicad_pcb, HE75.kicad_sch]
2025-01-08 Rename schematic section
    [HE75.kicad_sch]
2025-01-08 Update JLCPCB gerbers
    [HE75.kicad_pcb]
